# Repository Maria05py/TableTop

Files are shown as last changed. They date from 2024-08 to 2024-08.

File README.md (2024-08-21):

# TableTop
Documentación del proyecto "TableTop" para el evento ExpoCenfo de la Universidad Cenfotec. Este proyecto propone la creación de un prototipo de mesa multifuncional que maximiza el uso de sistemas ciberfísicos, promoviendo el bienestar y acercando la tecnología a distintas generaciones.

## Olimpiadas de Computación inteligente (ExpoCenfo)
El presente proyecto forma parte de uno de los tantos equipos participantes de las Olimpiadas de Computación inteligente, la cual corresponden a una competencia costarricense con sede en la Universidad Cenfotec, abierta a todos los estudiantes universitarios entusiastas de la tecnología que deseen aceptar el reto y competir en la mejor creación de un sistema ciberfísico. Dicho evento tiene lugar el día miércoles 21 de agosto con cede en la Universidad Cenfotec. El sitio oficial del evento, incluyendo las normativas y demás especificaciones, se encuentran en el siguiente enlace: [link](https://ucenfotec.ac.cr/expocenfo/).

## ¿Qué es TableTop?
Este proyecto se centra en una mesa con un display de luces LED, diseñada para ayudar a niños pequeños a mejorar su ansiedad, habilidades motoras y atención. La mesa utiliza sensores infrarrojos para encender, apagar y controlar las luces, lo que permite su uso en juegos de rapidez, concentración y diversas terapias. Además, se integra una aplicación móvil que permitirá cambiar las luces, seleccionar juegos y gestionar funciones básicas a través de tecnología RFID. A futuro también se contempla el uso de Alexa para comandos de voz, proporcionando instrucciones y funcionalidades accesibles para los más pequeños. Adicionalmente, se busca la posibilidad de actualizar juegos y características desde la nube, manteniendo la mesa al día con nuevas opciones. La mesa no es solo un espacio físico, sino un entorno terapéutico y de aprendizaje que utiliza tecnología avanzada para ofrecer experiencias cercanas al uso de la tecnología.
El propósito principal de esta mesa inteligente es crear un entorno seguro y atractivo para que los niños de la casa puedan aprender y relajarse al mismo tiempo. Permitiendo a los niños interactuar con la tecnología en un ambiente controlado, esta mesa inteligente permitirá a los más pequeños de la casa practicar sus habilidades tecnológicas y mejorar su enfoque a través de juegos interactivos y estimulantes a través del uso de luces LEDs, todo esto sin exponerlo a los niños a las redes sociales y aplicaciones con contenido inapropiado y violencia, permitiéndoles estar educados, entretenidos y seguros en el mundo online. 
Los beneficios de este proyecto para los niños de la casa son:

-**Desarrollo de habilidades cognitivas y motoras:** Esta mesa incorpora la diversión y el aprendizaje por medio de juegos que requieren concentración y resolución de problemas, como Tetris o patrones de luz, lo que les ayuda a desarrollar habilidades cognitivas como la memoria, la lógica, la concentración y el pensamiento crítico.

-**Habilidades Tecnológicas:** Ayuda a los niños a familiarizarse con la tecnología en un entorno seguro mientras les ayuda a desarrollar habilidades tecnológicas tempranas, lo que es crucial en el mundo actual.

-**Relajación por medio de estimulación sensorial controlada:** 
La luz suave y los patrones de color cambiantes crean un ambiente sensorial que promueve la calma y la concentración.

-**Aulas interactivas:** La mesa busca convertirse en una herramienta ideal para aulas interactivas, donde los estudiantes pueden participar en actividades grupales o individuales que fomenten la colaboración, la concentración y el aprendizaje a través de la tecnología. Para futuras aplicaciones nuestra mesa inteligente tiene el potencial de ser una herramienta poderosa no solo en el hogar, sino también en entornos educativos y terapéuticos.
****
El presente proyecto es un prototipo equipado con las funcionalidades básicas de: Conectarse a su debida aplicación, mostrar patrones de movimiento en el display LED y reaccionar ante los estímulos de los sensores infrarojos. 

## Índice de Contenido
1. [Organización del repositorio](#Organización-del-repositorio)
2. [Diseño 3D](#diseño-3d)
3. [Materiales no electrónicos](#materiales-no-electrónicos)
4. [Materiales electrónicos](#materiales-electrónicos)
5. [Pasos y creación ](#pasos-y-creación)
6. [Códigos y librerías empleadas](#códigos-y-librerías-empleadas)
7. [Usos y problemas detectados](#Usos-y-problemas-detectados)
8. [Licencia](#licencia)

## Carpetas y organización del repositorio:
**"Códigos":**
- Los archivos tipo C++, header, librerías y .ino necesarios para la correcta ejecución de las diferentes funcionalidades de la mesa.
- Módulos y librerías empleadas para la correcta ejecución del código principal.

**"Modelos3D":**
- Archivos correspondentes a las piezas a cortar por medio de la cortadora láser (Piezas_Superiores.skp)
- Archivos correspondientes al modelo 3D de la mesa completa (Base_mesa_en_melamina.skp)  

**"Licencia":**
- Licencia del presente proyecto y detalles sobre las restricciones correspondientes. 

**"APKs":**
- Archivo apk correspondiente a la debida aplicación de Table Top.
  
**"Documentos":**
- Presentación de los integrantes, detalles sobre el proyecto, implementación y resultados obtenidos.

**"Créditos y atribuciones":**
- Créditos sobre el contenido modifivado y utilizado dentro del código, además de los enlaces correspondientes al contenido original.

## Diseño 3D:
El diseño 3D, a cargo del estudiante Braulio Garro Marín, fue creado desde 0 en el software "SketchUp". A continuación se muestran las dimensiones y el diseño general de la mesa, además de las piezas a cortar para el acabado final, en este caso melamina. 

Imagen de WhatsApp 2024-06-18 a las 14 02 02_3d3d445a
Imagen de WhatsApp 2024-06-18 a las 14 02 02_32868ecb
Imagen de WhatsApp 2024-06-18 a las 14 02 03_3f1b13b2
Imagen de WhatsApp 2024-06-08 a las 18 51 28_593eec7b
Imagen de WhatsApp 2024-06-08 a las 18 51 59_6e4e2997
Imagen de WhatsApp 2024-08-16 a las 15 52 16_07ad1a83

## Materiales no electrónicos:
- Melamina (2500mm x 1830mm).
- MDF (122cm x 244cm).
- Lámina de acrílico de 7mm de grosor (66.4cm x 66.4cm).
- Polarizado translúcido (1m x 1m)
  
## Materiales electrónicos:
- Placa de desarrollo ESP32.
- Cargador de iones de litio multicelda 2S, 3S, 4S.
- uJPM TXS0108E 8-Channel Logic Level Bi-Directional Converter.
- Convertidor buck ajustable de 1000W.
- Tira de luces LED WS2811 (100 LEDs utilizados en este caso).
- Módulo de placa multiplexor digital analógico (7 utilizados en este caso).
- Módulo de sensor de evitación infrarrojo IR (x100 sensores de evitación en este caso).
- Módulo RFID.
- Etiqueta universal ultraligera de 25mm.
- Cable de cobre de distintos grosores.
- Estaño.
- Cables (Preferiblemente de gran cantidad de colores en pro de mejorar la simplicidad de los pasos). 
  
## Pasos y creación:
Una vez cortadas y listas las piezas, se procede a armar la mesa en su totalidad: Unión de cada parte de la melamina (base de la mesa), uniones entre los separadores de la matriz (correspondientes a las "dentaduras"), etc... 






1) Enlistados en orden, con respecto a los componentes electónicos, primeramente se deben de calibrar los 100 sensores infrarrojos para que los mismos reaccionen ante una distancia similar al momento de pasar la mano por encima de los infrarrojos correspondientes, esto se logra ajustando el "Distance Adjust" (Mirar la imagen de referencia).




(Uso de la protoboard para calibrar los 100 sensores infrarojos a utilizar. Se recomienda el uso de la protoboard para probar al menos 5-6 seonsores infrarojos a la vez en pro de agilizar el proceso de creación).

2) Seguidamente, se procede a cortar cable de 3 tres colores diferentes (En nuestro caso rojo, verde y negro) de 5cm, esto con el fin de "alargar" la tira de LEDs, de modo en la que los mismos encajen correctamente en las divisiones de la matriz (líneas de mdf). Estos colores se utilizan para conectar correctamente cada uno de los pines de la tira de LED (5V, GRN y DO) respectivamente. Como es lógico, primero se debe de cortar cada uno de los LEDs de forma en la que cada uno está "suelto".


   
Imagen de WhatsApp 2024-08-20 a las 17 43 21_59c6724c

A continuación, una imagen correspondiente a los pinouts, importante para obtener una mejor referencia, así como los colores y orientación utilizados, recordando la     utilización de cables de 5cm como separación.

 

Imagen de WhatsApp 2024-08-20 a las 17 44 42_55fda35c
(Imagen de referencia: Colores y lógica detrás de las conexiones entre los respectivos leds)



4) Luego, una vez preparados los LEDS, se deben de pegar con silicón caliente los 100 sensores infrarrojos a los separadores de la matriz. Seguidamente se sueldan los pines GND y 5+ entre sí (conectando cada pin con el del siguiente sensor, bajo la lógica GND -> GND del siguiente sensor, por ejemplo) como es posible observar en las siguientes fotografías. Una vez aplicada la corriente respectiva, y al haber calibrado correctamente cada uno de los infrarojos, debe activarse al acercar la mano, incluso tras utilizar el acrílico.


Imagen de WhatsApp 2024-08-11 a las 13 56 32_f2a4d858
Imagen de WhatsApp 2024-08-11 a las 13 56 32_85e9ffc6
Imagen de WhatsApp 2024-08-15 a las 14 14 28_cd028e31


5) Con el propósito de probar la lógica detrás de la matriz LED, fue utilizada una mini matriz de pruebas, la cual consiste en 10 tiras de 10 leds sin cortar ni alterar. A nivel de código fue utilizda la versión de "LEDMatrix.ino" editada por Matthew Kaye. El código original se puede encontrar en el siguiente enlace, el cual debe descargarse como .zip: https://github.com/N00d13/10x10_LED_MATRIX_ANIMATIONS. (Paso opcional). La lógica detrás de la conexiones se puede observar en las conexiones mostradas en la siguiente imagen:

placa de pruebas
Imagen de WhatsApp 2024-08-11 a las 13 56 32_20282ce5

6) Una vez probada la eficacia de la matriz LED, para crear el display final se colocan las respectivas tiras de LEDs previamente preparadas (en este caso, las tiras alteradas con su debida separación de 5cm) de forma en la cual cada led quede centrado con respecto a su respectiva. Las conexiones entre cada una de las tiras se encuentran escondidas debajo de la base, sin embargo, son las mismas mostradas en la mini matriz de prueba. 
   
Imagen de WhatsApp 2024-08-16 a las 23 11 40_c0f88f87
Imagen de WhatsApp 2024-08-16 a las 23 14 34_636a6f1e
(Antes de completar el proceso de montaje del display, se recomienda comprobar el estado de todos los LEDs de la matriz).

Imagen de WhatsApp 2024-08-17 a las 18 15 02_96942961
Imagen de WhatsApp 2024-08-18 a las 12 11 58_bb98c2f2
Imagen de WhatsApp 2024-08-18 a las 16 06 51_b8d5f709
(Proceso de creación de las animaciones de inicio de la aplicación)

7) Una vez se posean los LEDs debidamente pegados, se debe colocar por encima la matriz de MDF, de modo en la que es posible visualizar tanto la matriz de LEDs como el mapeado de infrarojos correspondiente. 

8) Es necesaria efectuar la conexión de los sensores infrarojos para el mapeado LED-Infrarojo, para esto, una vez conectados los dos pines anteriormente mencionados (GND y 5+) entre las distintas filas de infrarojos (paso número 4), es hora de soldar un cable de larga longitud a cada uno de los pines faltantes, el pin "out", de forma en la que posea un cable soldado de una única punta. El cable soldado va a sobresalir en forma de arco como en la siguiente fotografía, por ende, debe estar soldado solamente en el pin. 


9) Seguidamente, es necesario abrir un agujero al lado izquierdo de cada infrarojo, justo en la base donde se pegaron previamente los LEDs.
    
Imagen de WhatsApp 2024-08-20 a las 20 53 51_df8963d6

10) Aprovechando los agujeros abiertos, se debe de "pasar" el cable del pin out, de modo que el mismo se "oculte" y sea pasado por debajo la base, la cual contiene los LEDs.
    
Imagen de WhatsApp 2024-08-20 a las 20 53 50_c17e81a9
Imagen de WhatsApp 2024-08-20 a las 20 53 50_81a2a1f4

11) Seguidamente, se utilizan 7 multiplexors, de forma en la que se mapea cada infrarojo de 16 en 16, a modo de "mapear" e identificar cada uno de los LEDs según su ubicación y estado. Las siguientes imágenes ejemplifican la forma en la que se llevó a cabo este proceso de soldadura.

Imagen de WhatsApp 2024-08-20 a las 20 53 50_079f733d

11) Se coloca el polarizado translúcido encima del acrílico.

polarizado

13) Se deben cargar los respectivos códigos.


    
## Códigos, mapeados y librerías empleadas:

**"Librerías empleadas":**

- *FastLED*: Es necesaria la utilización de la presente librería para crear códigos eficientes, sencillos y optimizados que controlen diferentes modelos de tiras LED, como la WS2811, utilizada por nuestro grupo de trabajo. Esta librería permite trabajar con siglas de composición de los colores primarios (RGB por defecto) y alterarlos, ajustar la intensidad de los LEDs, emplear funciones rápidas y eficientes, superiores a las por defecto de Arduino. Creada por Daniel Garcia.
  
- *MFRC522*: Bilbioteca para la comunciación mediante RFID, haciendo posible la lectura y escritura de etiquetas RFID.
   
- *FastLED_NeoMatrix*: Extensión de FastLED, encargada de controlar la matriz de luces de manera más intuitiva.
  
- *Adafruit_GFX*: Biblioteca gráfica para el uso de LEDs en general. Funciona correctamente al utilizarla en conjunto con las bibliotecas anteriormente mencionadas.
  
- *BluetoothSerial*: Biblioteca encargada de permitir la comunicación Bluetooth mediante el ESP32. En este caso es utilizada para conectar el APK "TableTop".
  
- *LEDMatrix*: Biblioteca encargada de apoyar la lógica de la matriz y permitir el manejo de coordenadas de manera más sencilla.
  
- *LEDSprites*: Biblioteca encargada de permitir la manipulación de gráficos dentro de una matriz (Créditos a AaronLiddiment).
  
- *LEDText*: Biblioteca encargada de poder mostrar texto en la matriz lED (Créditos a AaronLiddiment).
  
- *FontMatrise*: Biblioteca encargada de ajustar la resolución y tipografía del texto mostrado dentro del tetris. 

**"Mapeado de los lEDs":**

La lógica (x,y) de la matriz LED de 10x10 es la siguiente:

	9,  10,  29,  30,  49,  50,  69,  70,  89,  90,
	8,  11,  28,  31,  48,  51,  68,  71,  88,  91,
	7,  12,  27,  32,  47,  52,  67,  72,  87,  92,
	6,  13,  26,  33,  46,  53,  66,  73,  86,  93,
	5,  14,  25,  34,  45,  54,  65,  74,  85,  94,
	4,  15,  24,  35,  44,  55,  64,  75,  84,  95,
	3,  16,  23,  36,  43,  56,  63,  76,  83,  96,
	2,  17,  22,  37,  42,  57,  62,  77,  82,  97,
	1,  18,  21,  38,  41,  58,  61,  78,  81,  98,
	0,  19,  20,  39,  40,  59,  60,  79,  80,  99

En casos en los que es necesario dibujar directamente sobre la matriz, es necesario conocer esta lógica. Además, en caso de mapear cada uno de los sensores, es indispensable conocer esta información. 

## Usos y problemas detectados:

- Se detecta alto nivel de consumo por parte del conjunto de LEDs e infrarojos. Si bien es posible ejecutar el código .ino y aprovechar todas las funcionalidades, no es posible hacer que el uso de baterías alimente correcta y prolongadamente el proyecto. Estos detalles quedan a revisión.
- Existen algunos conflictos con la lectura de la tarjeta RFID en algunos casos, sin embargo, se trata de un tema relacionado al código y al timing de lecturas.

## Participantes:
- Braulio Garro Marín
- María Jesús Rodríguez Molina
- Geisel Thais Hernández Quesada
- Melina Valeska Soto Badilla
  
## Licencia:
Este proyecto está licenciado bajo los términos de la Licencia Creative Commons. 



TableTop © 2024 by TableTop is licensed under CC BY-SA 4.0. To view a copy of this license, visit https://creativecommons.org/licenses/by-sa/4.0/

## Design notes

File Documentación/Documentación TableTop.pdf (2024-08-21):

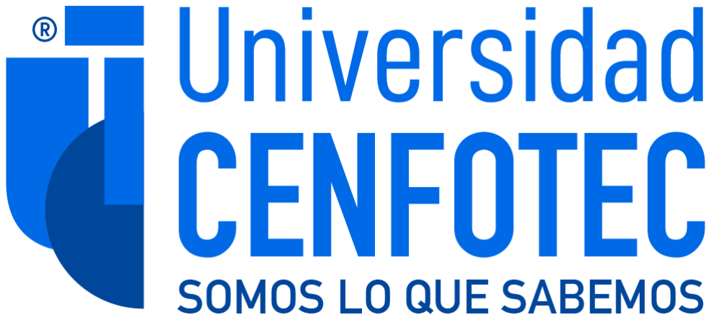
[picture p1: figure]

TableTop

Braulio Garro Marín

María Jesús Rodríguez Molina

Geisel Thais Hernández Quesada

Melina Valeska Soto Badilla

Universidad CENFOTEC

Olimpiadas Computacionales

Fecha: Agosto, 2024

## Índice

Índice | 2
Introducción | 3
Objetivos Específicos | 4
¿Qué es TableTop? | 5
Funcionalidades principales | 5
Fundamentos Tecnológicos Utilizados | 6
Enfoque en el Bienestar del Usuario | 7
Relevancia de nuestro proyecto en el contexto actual | 7
Futuras Aplicaciones | 8

## Introducción

El proyecto TableTop tiene como propósito principal crear un entorno seguro, atractivo y

estimulante para que los niños puedan aprender y relajarse. Esta mesa inteligente está

diseñada para integrar la tecnología de manera controlada en la vida de los más pequeños,

promoviendo tanto el desarrollo de habilidades cognitivas y motoras, como el bienestar

emocional a través de juegos interactivos y terapias basadas en luces LED. En un mundo

donde el acceso a la tecnología está al alcance de todos sin restricción alguna, hace que los

niños estén expuestos a grandes peligros cuando no son supervisados correctamente,

TableTop se presenta como una herramienta que les permite interactuar con dispositivos

tecnológicos de manera constructiva e integral, manteniéndolos seguros de la exposición

excesiva a redes sociales y contenido inapropiado.

Los beneficios de este proyecto para los niños de la casa son:

-Desarrollo de habilidades cognitivas y motoras:Esta mesa incorpora la diversión y el

aprendizaje por medio de juegos que requieren concentración y resolución de problemas,

como Tetris o patrones de luz, lo que les ayuda a desarrollar habilidades cognitivas como la

memoria, la lógica, la concentración y el pensamiento crítico.

-Habilidades Tecnológicas: Ayuda a los niños a familiarizarse con la tecnología en un

entorno seguro mientras les ayuda a desarrollar habilidades tecnológicas tempranas, lo que

es crucial en el mundo actual.

-Relajación por medio de estimulación sensorial controlada: La luz suave y los patrones de

color cambiantes crean un ambiente sensorial que promueve la calma y la concentración.

## Olimpiadas de Computación inteligente (ExpoCenfo)

El presente proyecto forma parte de uno de los tantos equipos participantes de las

Olimpiadas de Computación inteligente, la cual corresponden a una competencia

costarricense con sede en la Universidad Cenfotec, abierta a todos los estudiantes

universitarios entusiastas de la tecnología que deseen aceptar el reto y competir en la mejor

creación de un sistema ciberfísico. Dicho evento tiene lugar el día miércoles 21 de agosto

con sede en la Universidad Cenfotec. El sitio oficial del evento, incluyendo las normativas y

demás especificaciones, se encuentran en el siguiente enlace: link.

## Objetivos Específicos

- Crear una herramienta funcional que beneficie tanto a niños como adultos en el

desarrollo y mejora del pensamiento crítico, de habilidades cognitivas, motoras y de

concentración.

- Promover el uso de tecnologías en el aprendizaje de forma sana e integral.
- Construir una herramienta que funcione tanto en los hogares como en las escuelas

con la función de promover ambientes tranquilos y estimulantes que ayudan a los

usuarios que la utilizan a calmar la ansiedad por medio de juegos de concentración y

luces led.

## ¿Qué es TableTop?

Este proyecto se centra en una mesa interactiva equipada con un display de cien luces LED

y sensores infrarrojos, diseñada para ayudar a niños pequeños a mejorar su ansiedad,

habilidades motoras y atención. La mesa utiliza sensores infrarrojos para encender, apagar

y controlar las luces, lo que permite su uso en juegos de rapidez, concentración y diversas

terapias. Además, se integra una aplicación móvil que permitirá cambiar las luces,

seleccionar juegos y gestionar funciones básicas a través de tecnología RFID.A través de

juegos que requieren rapidez, concentración y habilidades motoras, la mesa ofrece una

plataforma de aprendizaje y relajación.

Funcionalidades principales:

- Sensores infrarrojos: Estos sensores controlan el encendido y apagado de las

luces LED, permitiendo que los niños interactúen con la mesa mediante gestos

simples, como colocar la mano sobre los sensores.

- Aplicación móvil y tecnología RFID: La mesa se integra con una aplicación móvil

que permite cambiar los patrones de luces, seleccionar juegos y gestionar funciones

básicas. Además, la tecnología RFID facilita el acceso a funciones personalizadas y

seguras.

Además, a futuro se espera la integración de las siguientes funcionalidades:

- Comandos de voz con Alexa (futuro): Se contempla la integración de comandos

de voz mediante Alexa, facilitando el acceso a instrucciones y juegos para los más

pequeños.

- Actualizaciones en la nube: Se busca que la mesa pueda mantener

actualizaciones de su juegos y características desde la nube, manteniendo la mesa al día con nuevas opciones y asegurando las mejores prácticas de seguridad para

siempre resguardar la integridad del usuario.

TableTop no es solo un objeto físico, sino un entorno terapéutico y de aprendizaje avanzado,

diseñado para brindar experiencias positivas con la tecnología, alejadas de los peligros del

mundo online.

## Fundamentos Tecnológicos Utilizados

El desarrollo de TableTop se basó en una combinación de tecnologías avanzadas que

permiten su funcionamiento seguro y efectivo:

- Luces LED: Utilizadas para crear patrones visuales interactivos que estimulan el

aprendizaje y la relajación.

- Sensores infrarrojos: Detectan la presencia de la mano del niño para activar los

juegos y las respuestas visuales.

- Tecnología RFID: Se utiliza para mostrar imagenes de inicio y finalización
- Aplicación móvil: Facilita la interacción remota con la mesa, permitiendo a los

padres o educadores ajustar los juegos y las actividades.

- Conectividad con la nube: Utilizado para mantener a la mesa siempre actualizada

con los últimos juegos y terapias disponibles.

- Integración con asistentes de voz (Alexa): Facilita la interacción con la mesa

mediante comandos de voz, haciendo que las funciones sean accesibles incluso

para los más pequeños.

## Enfoque en el Bienestar del Usuario

El bienestar individual y comunitario es el eje central de TableTop. Este proyecto se propone

brindar espacios donde los niños puedan relajarse y aprender seguramente. Una luz suave

con patrones interactivos está diseñada para reducir la ansiedad y mejorar la concentración,

mientras que los juegos promueven habilidades cognitivas y motoras sin necesidad de

exposición a redes sociales o juegos con contenido inapropiado.TableTop tiene un fuerte

enfoque en el bienestar comunitario, ya que está pensada para poder ser usada tanto en los

hogares como en entornos educativos y terapéuticos; por lo tanto, el potencial de este

proyecto para ayudar a una amplia gama de usuarios es enorme. Desde familias que

buscan un entorno seguro para sus hijos hasta escuelas y centros de terapia que desean

integrar la tecnología en su trabajo.

## Relevancia de nuestro proyecto en el contexto actual

En la actualidad, el uso de las tecnologías en la educación ha ido en incremento, sin

embargo, el uso apropiado de estas se ha visto afectado por el auge de las redes sociales,

de los videojuegos violentos y todo tipo de aplicaciones que en lugar de promover el

desarrollo integral de los infantes, lo detiene.Por esa razón, el desarrollo de una herramienta

tan versátil como TableTop, que se puede utilizar para desarrollar las habilidades motoras,

de concentración y cognitivas de los niños y niñas de una forma segura y estimulante, es

tan importante.Esto la posiciona como una herramienta vital en esta creciente era digital. El

gran espectro de usos que tiene TableTop lo convierte en una herramienta importante por su

capacidad para mejorar el bienestar individual y comunitario. En un momento en que la

salud mental y la educación personalizada son prioridades crecientes, TableTop ofrece una

solución que integra ambas en un único dispositivo.

## Futuras Aplicaciones

TableTop tiene el potencial de evolucionar y adaptarse a nuevas necesidades y contextos:

- Aulas Interactivas: Convertir la mesa en una herramienta educativa en el aula,

donde los estudiantes puedan participar en actividades grupales e individuales,

fomentando la colaboración y el aprendizaje.

- Terapia para Niños con Necesidades Especiales: Aplicar las funcionalidades de la

mesa para ayudar a niños con condiciones como el autismo o el TDAH, utilizando la

luz y los juegos para mejorar su enfoque y reducir la ansiedad.

- Expansión de Juegos y Terapias: A través de actualizaciones en la nube, TableTop

puede seguir ofreciendo nuevas experiencias que mantengan a los niños

comprometidos y aprendiendo de manera segura.

El propósito principal de esta mesa inteligente es crear un entorno seguro y atractivo para

que los niños de la casa puedan aprender y relajarse al mismo tiempo. Permitiendo a los

niños interactuar con la tecnología en un ambiente controlado, esta mesa inteligente

permitirá a los más pequeños de la casa practicar sus habilidades tecnológicas y mejorar su

enfoque a través de juegos interactivos y estimulantes a través del uso de luces LEDs, todo

esto sin exponerlo a los niños a las redes sociales y aplicaciones con contenido inapropiado

y violencia, permitiéndoles estar educados, entretenidos y seguros en el mundo online.

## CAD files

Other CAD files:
Modelos3D/Base_mesa_en_melamina.skp
Modelos3D/Piezas_Superiores.skp

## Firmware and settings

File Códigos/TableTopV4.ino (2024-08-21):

// Archivos y librerías necesarias para el funcionamiento del proyecto

#include <SPI.h>
#include <MFRC522.h>
#include <FastLED.h>
#include <FastLED_NeoMatrix.h>
#include <Adafruit_GFX.h>
#include "BluetoothSerial.h" 
#include <LEDMatrix.h>
#include <LEDSprites.h>
#include <LEDText.h>
#include <FontMatrise.h>

#include "Plasma.cpp" 
#include "Lines.cpp"
#include "InterruptHandler.h"

#define DATA_PIN 27 //Pin utilizado en la placa (En este caso ESP32)
#define WIDTH 10 //Ancho de la matriz
#define HEIGHT 10 //Altura de la matriz
#define NUM_LEDS WIDTH * HEIGHT //Tamaño total de la matriz
#define BRIGHTNESS 240 //Brillo o intensidad de la matriz, recordando que el máximo es 255
#define FRAMES_PER_SECOND  120 //Dato necesario para el método doMultipleAnimations. Mientras más bajo el número, más lenta la animación.

//Codigo para tetris

#define LED_PIN        27
#define COLOR_ORDER    GRB
#define CHIPSET        WS2811
#define MATRIX_WIDTH   10
#define MATRIX_HEIGHT  10
#define MATRIX_TYPE    HORIZONTAL_MATRIX

CRGB leds[NUM_LEDS];

// Pines de control para los multiplexores
const int muxS0 = 26;  // Pin de selección S0
const int muxS1 = 25;  // Pin de selección S1
const int muxS2 = 33;  // Pin de selección S2
const int muxS3 = 32;  // Pin de selección S3

const int muxSIG[] = {13, 12, 35, 34, 15, 2, 4}; // Array de pines de señal para 7 multiplexores

// Cambiado de WS2812B a WS2811 ya que esta es la tira LED utilizada para el proyecto
FastLED_NeoMatrix *matrix = new FastLED_NeoMatrix(leds, 10, HEIGHT, WIDTH/10, 1, 
  NEO_MATRIX_BOTTOM     + NEO_MATRIX_LEFT +
    NEO_MATRIX_COLUMNS + NEO_MATRIX_PROGRESSIVE + 
    NEO_TILE_BOTTOM + NEO_TILE_LEFT +  NEO_TILE_PROGRESSIVE);

cLEDMatrix<MATRIX_WIDTH, -MATRIX_HEIGHT, MATRIX_TYPE> ledsTetris;


#define TARGET_FRAME_TIME    15  // Desired update rate, though if too many leds it will just run as fast as it can!
#define INITIAL_DROP_FRAMES  20  // Start of game block drop delay in frames

// Bluetooth input
enum btnInput {NONE, ROTATE, DOWN, LEFT, RIGHT};
btnInput currentInput = NONE;

const uint8_t TetrisIData[] = 
{
  // Frame 1
  B8_3BIT(00000000),
  B8_3BIT(00000000),
  B8_3BIT(00000000),
  B8_3BIT(11110000),
  // Frame 2
  B8_3BIT(10000000),
  B8_3BIT(10000000),
  B8_3BIT(10000000),
  B8_3BIT(10000000),
  // Frame 3
  B8_3BIT(00000000),
  B8_3BIT(00000000),
  B8_3BIT(00000000),
  B8_3BIT(11110000),
  // Frame 4
  B8_3BIT(10000000),
  B8_3BIT(10000000),
  B8_3BIT(10000000),
  B8_3BIT(10000000)
};
const uint8_t TetrisIMask[] = 
{
  // Frame 1
  B8_1BIT(00000000),
  B8_1BIT(00000000),
  B8_1BIT(00000000),
  B8_1BIT(11110000),
  // Frame 2
  B8_1BIT(10000000),
  B8_1BIT(10000000),
  B8_1BIT(10000000),
  B8_1BIT(10000000),
  // Frame 3
  B8_1BIT(00000000),
  B8_1BIT(00000000),
  B8_1BIT(00000000),
  B8_1BIT(11110000),
  // Frame 4
  B8_1BIT(10000000),
  B8_1BIT(10000000),
  B8_1BIT(10000000),
  B8_1BIT(10000000)
};
const uint8_t TetrisJData[] = 
{
  // Frame 1
  B8_3BIT(00000000),
  B8_3BIT(00000000),
  B8_3BIT(22200000),
  B8_3BIT(00200000),
  // Frame 2
  B8_3BIT(00000000),
  B8_3BIT(02000000),
  B8_3BIT(02000000),
  B8_3BIT(22000000),
  // Frame 3
  B8_3BIT(00000000),
  B8_3BIT(00000000),
  B8_3BIT(20000000),
  B8_3BIT(22200000),
  // Frame 4
  B8_3BIT(00000000),
  B8_3BIT(22000000),
  B8_3BIT(20000000),
  B8_3BIT(20000000)
};
const uint8_t TetrisJMask[] = 
{
  // Frame 1
  B8_1BIT(00000000),
  B8_1BIT(00000000),
  B8_1BIT(11100000),
  B8_1BIT(00100000),
  // Frame 2
  B8_1BIT(00000000),
  B8_1BIT(01000000),
  B8_1BIT(01000000),
  B8_1BIT(11000000),
  // Frame 3
  B8_1BIT(00000000),
  B8_1BIT(00000000),
  B8_1BIT(10000000),
  B8_1BIT(11100000),
  // Frame 4
  B8_1BIT(00000000),
  B8_1BIT(11000000),
  B8_1BIT(10000000),
  B8_1BIT(10000000)
};
const uint8_t TetrisLData[] = 
{
  // Frame 1
  B8_3BIT(00000000),
  B8_3BIT(00000000),
  B8_3BIT(33300000),
  B8_3BIT(30000000),
  // Frame 2
  B8_3BIT(00000000),
  B8_3BIT(33000000),
  B8_3BIT(03000000),
  B8_3BIT(03000000),
  // Frame 3
  B8_3BIT(00000000),
  B8_3BIT(00000000),
  B8_3BIT(00300000),
  B8_3BIT(33300000),
  // Frame 4
  B8_3BIT(00000000),
  B8_3BIT(30000000),
  B8_3BIT(30000000),
  B8_3BIT(33000000)
};
const uint8_t TetrisLMask[] = 
{
  // Frame 1
  B8_1BIT(00000000),
  B8_1BIT(00000000),
  B8_1BIT(11100000),
  B8_1BIT(10000000),
  // Frame 2
  B8_1BIT(00000000),
  B8_1BIT(11000000),
  B8_1BIT(01000000),
  B8_1BIT(01000000),
  // Frame 3
  B8_1BIT(00000000),
  B8_1BIT(00000000),
  B8_1BIT(00100000),
  B8_1BIT(11100000),
  // Frame 4
  B8_1BIT(00000000),
  B8_1BIT(10000000),
  B8_1BIT(10000000),
  B8_1BIT(11000000)
};
const uint8_t TetrisOData[] = 
{
  // Frame 1
  B8_3BIT(00000000),
  B8_3BIT(00000000),
  B8_3BIT(44000000),
  B8_3BIT(44000000),
  // Frame 2
  B8_3BIT(00000000),
  B8_3BIT(00000000),
  B8_3BIT(44000000),
  B8_3BIT(44000000),
  // Frame 3
  B8_3BIT(00000000),
  B8_3BIT(00000000),
  B8_3BIT(44000000),
  B8_3BIT(44000000),
  // Frame 4
  B8_3BIT(00000000),
  B8_3BIT(00000000),
  B8_3BIT(44000000),
  B8_3BIT(44000000)
};
const uint8_t TetrisOMask[] = 
{
  // Frame 1
  B8_1BIT(00000000),
  B8_1BIT(00000000),
  B8_1BIT(11000000),
  B8_1BIT(11000000),
  // Frame 2
  B8_1BIT(00000000),
  B8_1BIT(00000000),
  B8_1BIT(11000000),
  B8_1BIT(11000000),
  // Frame 3
  B8_1BIT(00000000),
  B8_1BIT(00000000),
  B8_1BIT(11000000),
  B8_1BIT(11000000),
  // Frame 4
  B8_1BIT(00000000),
  B8_1BIT(00000000),
  B8_1BIT(11000000),
  B8_1BIT(11000000)
};
const uint8_t TetrisSData[] = 
{
  // Frame 1
  B8_3BIT(00000000),
  B8_3BIT(00000000),
  B8_3BIT(05500000),
  B8_3BIT(55000000),
  // Frame 2
  B8_3BIT(00000000),
  B8_3BIT(50000000),
  B8_3BIT(55000000),
  B8_3BIT(05000000),
  // Frame 3
  B8_3BIT(00000000),
  B8_3BIT(00000000),
  B8_3BIT(05500000),
  B8_3BIT(55000000),
  // Frame 4
  B8_3BIT(00000000),
  B8_3BIT(50000000),
  B8_3BIT(55000000),
  B8_3BIT(05000000)
};
const uint8_t TetrisSMask[] = 
{
  // Frame 1
  B8_1BIT(00000000),
  B8_1BIT(00000000),
  B8_1BIT(01100000),
  B8_1BIT(11000000),
  // Frame 2
  B8_1BIT(00000000),
  B8_1BIT(10000000),
  B8_1BIT(11000000),
  B8_1BIT(01000000),
  // Frame 3
  B8_1BIT(00000000),
  B8_1BIT(00000000),
  B8_1BIT(01100000),
  B8_1BIT(11000000),
  // Frame 4
  B8_1BIT(00000000),
  B8_1BIT(10000000),
  B8_1BIT(11000000),
  B8_1BIT(01000000)
};
const uint8_t TetrisTData[] = 
{
  // Frame 1
  B8_3BIT(00000000),
  B8_3BIT(00000000),
  B8_3BIT(66600000),
  B8_3BIT(06000000),
  // Frame 2
  B8_3BIT(00000000),
  B8_3BIT(06000000),
  B8_3BIT(66000000),
  B8_3BIT(06000000),
  // Frame 3
  B8_3BIT(00000000),
  B8_3BIT(00000000),
  B8_3BIT(06000000),
  B8_3BIT(66600000),
  // Frame 4
  B8_3BIT(00000000),
  B8_3BIT(60000000),
  B8_3BIT(66000000),
  B8_3BIT(60000000)
};
const uint8_t TetrisTMask[] = 
{
  // Frame 1
  B8_1BIT(00000000),
  B8_1BIT(00000000),
  B8_1BIT(11100000),
  B8_1BIT(01000000),
  // Frame 2
  B8_1BIT(00000000),
  B8_1BIT(01000000),
  B8_1BIT(11000000),
  B8_1BIT(01000000),
  // Frame 3
  B8_1BIT(00000000),
  B8_1BIT(00000000),
  B8_1BIT(01000000),
  B8_1BIT(11100000),
  // Frame 4
  B8_1BIT(00000000),
  B8_1BIT(10000000),
  B8_1BIT(11000000),
  B8_1BIT(10000000)
};
const uint8_t TetrisZData[] = 
{
  // Frame 1
  B8_3BIT(00000000),
  B8_3BIT(00000000),
  B8_3BIT(77000000),
  B8_3BIT(07700000),
  // Frame 2
  B8_3BIT(00000000),
  B8_3BIT(07000000),
  B8_3BIT(77000000),
  B8_3BIT(70000000),
  // Frame 3
  B8_3BIT(00000000),
  B8_3BIT(00000000),
  B8_3BIT(77000000),
  B8_3BIT(07700000),
  // Frame 4
  B8_3BIT(00000000),
  B8_3BIT(07000000),
  B8_3BIT(77000000),
  B8_3BIT(70000000)
};
const uint8_t TetrisZMask[] = 
{
  // Frame 1
  B8_1BIT(00000000),
  B8_1BIT(00000000),
  B8_1BIT(11000000),
  B8_1BIT(01100000),
  // Frame 2
  B8_1BIT(00000000),
  B8_1BIT(01000000),
  B8_1BIT(11000000),
  B8_1BIT(10000000),
  // Frame 3
  B8_1BIT(00000000),
  B8_1BIT(00000000),
  B8_1BIT(11000000),
  B8_1BIT(01100000),
  // Frame 4
  B8_1BIT(00000000),
  B8_1BIT(01000000),
  B8_1BIT(11000000),
  B8_1BIT(10000000)
};

#define TETRIS_SPR_WIDTH  4
#define TETRIS_SPR_HEIGHT 4
const uint8_t *TetrisSprData[] = { TetrisIData, TetrisJData, TetrisLData, TetrisOData, TetrisSData, TetrisTData, TetrisZData };
const uint8_t *TetrisSprMask[] = { TetrisIMask, TetrisJMask, TetrisLMask, TetrisOMask, TetrisSMask, TetrisTMask, TetrisZMask};
const struct CRGB TetrisColours[] = { CRGB(0, 255, 255), CRGB(0, 0, 255), CRGB(255, 165, 0), CRGB(255, 255, 0), CRGB(50, 205, 50), CRGB(255, 0, 255), CRGB(255, 0, 0) };

uint8_t PlayfieldData[MATRIX_HEIGHT * ((MATRIX_WIDTH + 7) / 8) * _3BIT];
uint8_t PlayfieldMask[MATRIX_HEIGHT * ((MATRIX_WIDTH + 7) / 8) * _1BIT];
uint8_t CompletedLinesData[TETRIS_SPR_HEIGHT * ((MATRIX_WIDTH + 7) / 8) * _1BIT];
const struct CRGB CompletedLinesColour[] = { CRGB(255, 255, 255) };
cSprite Playfield, CompletedLines, CurrentBlock;
cLEDSprites Sprites(&ledsTetris);

unsigned char AttractMsg[144], GameOverMsg[88];
char BlankMsg[32];
cLEDText TetrisMsg;

uint8_t DropDelay;
boolean AttractMode, NextBlock;
int16_t TotalLines;
unsigned int HighScore = 0, LastScore;

uint16_t PlasmaTime, PlasmaShift;
uint32_t LoopDelayMS, LastLoop;

//Termina el bloque encargado de trabajar el codigo para tetris

// Empieza el bloque de código para el uso de RFID
#define SS_PIN 5
#define RST_PIN 22
MFRC522 mfrc522(SS_PIN, RST_PIN);  // Crear objeto MFRC522

// Código del "MAIN"
bool cardPresent = false;  // Estado de la tarjeta (si está presente o no)
bool lastCardPresent = false; // Estado previo de la tarjeta

BluetoothSerial SerialBT;

// Colores de texto en un ciclo
const uint16_t colors[] = {
  matrix->Color(255, 87, 51), // Naranja
  matrix->Color(0, 128, 128), // Teal
  matrix->Color(255, 20, 147), // Rosado
  matrix->Color(165, 42, 42)  // Marrón
}; 

bool bluetoothInterrupt = false;
int amountColours = 4; // Número de colores en el ciclo
int x = WIDTH; // Posición inicial del texto
int pass = 0;  // Control para el ciclo de colores
bool firstCardPresent = false;
unsigned long previousMillis = 0;    // Variable para almacenar el tiempo anterior
const long RFIDinterval = 1000;          // Intervalo de 1000 ms (1 segundo)

int SensorMapping[100] = {
  1, 20, 21, 31, 41, 51, 61, 71, 81, 91, 
  2, 19, 22, 32, 42, 52, 62, 72, 82, 92, 
  3, 18, 23, 33, 43, 53, 63, 73, 83, 93, 
  4, 17, 24, 34, 44, 54, 64, 74, 84, 94, 
  5, 16, 25, 35, 45, 55, 65, 75, 85, 95, 
  6, 15, 26, 36, 46, 56, 66, 76, 86, 96, 
  7, 14, 27, 37, 47, 57, 67, 77, 87, 97, 
  8, 13, 28, 38, 48, 58, 68, 78, 88, 98, 
  9, 12, 29, 39, 49, 59, 69, 79, 89, 99, 
  10, 11, 30, 40, 50, 60, 70, 80, 90, 100
};

int sensorState[100];

void setup() {
//Codigo set Multiplexores
  pinMode(muxS0, OUTPUT);
  pinMode(muxS1, OUTPUT);
  pinMode(muxS2, OUTPUT);
  pinMode(muxS3, OUTPUT);
  // Configurar los pines de señal de los multiplexores como entrada
  for (int i = 0; i < 7; i++) {
    pinMode(muxSIG[i], INPUT);
  }

    //Set up Bluetooth
    Serial.begin(115200);
    SPI.begin();  // Iniciar SPI sin especificar pines (Si al compilar sale un error relacionado, no tiene importancia)
    mfrc522.PCD_Init();  // Iniciar MFRC522
    SerialBT.begin("TableTop_BT");
    Serial.println("The device is ready to pair!");
    // Cambiado WS2812B a WS2811 para tu tira LED específica
    FastLED.addLeds<WS2811, DATA_PIN, GRB>(leds, NUM_LEDS); // Configuración específica para WS2811
    matrix->begin(); //Sets up matrix
    matrix->setTextWrap(false);
    matrix->setBrightness(BRIGHTNESS);
    matrix->setTextColor(colors[pass]); // Inicializa con el primer color

	// Recordar los siguientes datos
    //Tetris SETUP
    //Serial.begin(115200); 
    //SerialBT.begin("ESP32Tetris");
    
    //FastLED.addLeds<CHIPSET, LED_PIN, COLOR_ORDER>(ledsTetris[0], ledsTetris.Size());
    //FastLED.setBrightness(200);
    //FastLED.clear(true);
    //FastLED.show();

    memset(PlayfieldData, 0, sizeof(PlayfieldData));
    memset(PlayfieldMask, 0, sizeof(PlayfieldMask));
    Playfield.Setup(ledsTetris.Width(), ledsTetris.Height(), PlayfieldData, 1, _3BIT, TetrisColours, PlayfieldMask);
    Playfield.SetPositionFrameMotionOptions(0, 0, 0, 0, 0, 0, 0, 0, 0);
    Sprites.AddSprite(&Playfield);

    memset(CompletedLinesData, 0, sizeof(CompletedLinesData));
    CompletedLines.Setup(ledsTetris.Width(), TETRIS_SPR_HEIGHT, CompletedLinesData, 1, _1BIT, CompletedLinesColour, CompletedLinesData);
    CompletedLines.SetPositionFrameMotionOptions(0, 0, 0, 0, 0, 0, 0, 0, 0);

    TetrisMsg.SetFont(MatriseFontData);
    sprintf((char *)BlankMsg, "%.*s", _min(((ledsTetris.Height() + TetrisMsg.FontHeight()) / (TetrisMsg.FontHeight() + 1)), (int)sizeof(BlankMsg) - 1), "                              ");
    sprintf((char *)AttractMsg, "%sTETRIS%sSCORE %u%sHIGH %u%sANY BUTTON TO START%s", BlankMsg, BlankMsg, LastScore, BlankMsg, (int)HighScore, BlankMsg, BlankMsg);
    TetrisMsg.Init(&ledsTetris, TetrisMsg.FontWidth() + 1, ledsTetris.Height(), (ledsTetris.Width() - TetrisMsg.FontWidth()) / 2, 0);
    TetrisMsg.SetBackgroundMode(BACKGND_LEAVE);
    TetrisMsg.SetScrollDirection(SCROLL_UP);
    TetrisMsg.SetTextDirection(CHAR_UP);
    TetrisMsg.SetFrameRate(1);
    TetrisMsg.SetOptionsChangeMode(INSTANT_OPTIONS_MODE);
    TetrisMsg.SetText(AttractMsg, strlen((const char *)AttractMsg));
    AttractMode = true;
    LoopDelayMS = TARGET_FRAME_TIME;
    LastLoop = millis() - LoopDelayMS;
    PlasmaShift = (random8(0, 5) * 32) + 64;
    PlasmaTime = 0;

    //En of Tetris SETUP

    FastLED.clear();
}

void loop() {
  //doPlasma(); 
  doSpell("TableTop", -55);
  if (SerialBT.available()) {    // Check if data is available on Bluetooth
    String receivedData = "";    // Variable to hold the received data

    while (SerialBT.available()) {
      receivedData += (char)SerialBT.read();  // Read data byte by byte
      delay(20); // Delay to allow more data to be read if coming in a stream
      
    }

    Serial.println("Received via Bluetooth: " + receivedData); // Print received data to serial port

    // Call the appropriate function based on receivedData
    selectFunction(receivedData);
    //retona a la vista de TableTop
        while (true) {
      if (checkForBluetoothInterrupt()) { // Verifica si hay interrupción
        break; // Sal del bucle si hay datos disponibles en Bluetooth
      }
      doSpell("TableTop", -55);
    }
  }

  cardPresent = mfrc522.PICC_IsNewCardPresent() && mfrc522.PICC_ReadCardSerial();

    // Obtener el tiempo actual
  unsigned long currentMillis = millis();

  if (cardPresent && !lastCardPresent) {
    if (!firstCardPresent) {
      // Si es la primera vez que se coloca la tarjeta
      Serial.println("Card Present"); 
      selectFunction("cardPresent");
      firstCardPresent = true;
    } else {
      // Si es la segunda vez que se coloca la tarjeta
      Serial.println("Card absent");
      selectFunction("cardAbsent");
      firstCardPresent = false;
    }
  }

  if (currentMillis - previousMillis >= RFIDinterval) {
    previousMillis = currentMillis; // Actualizar el tiempo anterior
    lastCardPresent = cardPresent;  // Actualizar el estado previo
    mfrc522.PICC_HaltA();
  }
}

void selectFunction(String data) {
  if (data == "i") {
    while (true) {
      if (checkForBluetoothInterrupt()) { // Verifica si hay interrupción
        break; // Sale del bucle si hay datos disponibles en Bluetooth
      }
      doSpell("TableTop", -55); // Muestra el texto "TableTop"
    }
    
  } else if (data == "p") {
    while (true) {
      if (checkForBluetoothInterrupt()) { // Verifica si hay interrupción
        break; // Sale del bucle si hay datos disponibles en Bluetooth
      }
      doPlasma(); // Ejecuta la función
    }
    } else if (data == "m") { // Lee sensores y controla LEDs
    while (true) {
      if (checkForBluetoothInterrupt()) { // Se verifica si hay interrupción
        break; // Sale del bucle si hay datos disponibles en Bluetooth
      }

      // Leer el estado de los sensores
      leerSensores();

      // Controlar los LEDs según el estado de los sensores
      controlarLEDs();

      // Mantener el estado de los LEDs durante 1 segundo
      delay(100);
    }
  } else if (data == "l") {
    while (true) {
      if (checkForBluetoothInterrupt()) { // Verifica si hay interrupción
        break; // Sal del bucle si hay datos disponibles en Bluetooth
      }
      doLines(); // Ejecuta la función
    }
  } else if (data == "cardPresent") {
    // Ejecuta secuencia de caras cuando la tarjeta está presente
    draw_face1();
    delay(1000);
    text_1();
    delay(1000);

    draw_face2();
    delay(1000);
    text_2();
    delay(1000);

    draw_face3();
    delay(1000);
    text_3();
    delay(1000);

    draw_face4();
    delay(1000);
    text_4();
    delay(1000);
  } else if (data == "cardAbsent") {
    // Ejecuta la animación de despedida cuando la tarjeta no está presente
    draw_sadface1();
    delay(1000);
    draw_sadface2();
    delay(1000); 
    draw_sadface3();
    delay(1000);
    draw_sadface4();
    delay(1000);
    FastLED.clear();
  } else if (data == "t") { //tetr
    bool Gamestatus = true;
      FastLED.addLeds<CHIPSET, LED_PIN, COLOR_ORDER>(ledsTetris[0], ledsTetris.Size());
      FastLED.setBrightness(BRIGHTNESS);
      FastLED.clear(true);
      FastLED.show();
    while (true) {

      Gamestatus = processGameLogic(); // Usa processGameLogic() para determinar el estado del bucle
      if (!Gamestatus) {
        break; // Sal del bucle si processGameLogic() devuelve false
      }
    }
  } else {
    Serial.println("Invalid option received.");
  }
}

void doPlasma() {
    Plasma plasma(leds, WIDTH, HEIGHT);
    plasma.start();
    FastLED.clear(); // Limpia la pantalla después de la animación
}


void doLines() {
    Lines lines(leds, WIDTH, HEIGHT);
    lines.start();
    FastLED.clear(); // Limpia la pantalla después de la animación
}

//doPlasma2 is modified from LDIRKO's Pastbin code found at this link: https://pastebin.com/6xT72A46

void doPlasma2(){
  int plasmaBrightness = 240; //The brightness is lower for doPlasma2. Change the added amount to BRIGHTNESS to your desire.
  int plasmaSpeed = 7; //Speed that the plasma changes colours, larger is slower  
  for (uint16_t time = 0, cycles = 0; cycles < 6521; time += 128, cycles++) { //Cycle is amount of time the animations runs. This runs for ~60 seconds
    uint16_t ms = millis();
    for (int i = 0; i < HEIGHT; i++) {
      for (int j = 0; j < WIDTH; j++) {
        uint8_t index = inoise8(i * 41, j * 41, ms / plasmaSpeed);  // x and y not change, only change z value with time increment for nice plasma looking noise original 4
        leds[XYNumberFind(i, j)] = CHSV((index + ms / 200) % 255, 255, plasmaBrightness); // within palette
      }
    }
    FastLED.delay(1);
  }
  FastLED.clear(); //clears matrix for next animation
}

uint8_t XYNumberFind(uint8_t x, uint8_t y) { return (y * WIDTH + x);}    //Function to find LED coordinates in LED matrix, 

//Next Part is for the multiple animations that are meshed together
//It is a modified version of the FASTLED example library, "DemoReal100"

// Forward declaration for addGlitter to ensure it's recognized before being used
void addGlitter(fract8 chanceOfGlitter);

typedef void (*SimplePatternList[])();
SimplePatternList gPatterns = {rainbow, rainbow, rainbowWithGlitter, confetti, sinelon, juggle, bpm };

uint8_t gCurrentPatternNumber = 0; // Index number of which pattern is current
uint8_t gHue = 0; // rotating "base color" used by many of the patterns

void doMultipleAnimations(){
  gCurrentPatternNumber = 0; // resets the pattern number to 0 every time doMultipleAnimations is called
  bool animationsFinished = false;
  int amountAnimations = 0;
  while(animationsFinished == false){
    gPatterns[gCurrentPatternNumber]();
    // send the 'leds' array out to the actual LED strip
    FastLED.show();  
    // insert a delay to keep the framerate modest
    FastLED.delay(1000/FRAMES_PER_SECOND); 
    // do some periodic updates
    EVERY_N_MILLISECONDS( 20 ) { gHue++; } // cycles the base color through the rainbow
    EVERY_N_SECONDS( 25 ){ // changes animation every n seconds
      nextPattern(); 
      amountAnimations++;
    } 
    if(amountAnimations == 7){
      animationsFinished = true;
    }
  }
  FastLED.clear(); //clears matrix for next animation
}

#define ARRAY_SIZE(A) (sizeof(A) / sizeof((A)[0]))

void nextPattern()
{
  // add one to the current pattern number, and wrap around at the end
  gCurrentPatternNumber = (gCurrentPatternNumber + 1) % ARRAY_SIZE( gPatterns);
}

void rainbow() 
{
  // FastLED's built-in rainbow generator
  fill_rainbow( leds, NUM_LEDS, gHue, 7);
}

void rainbowWithGlitter() 
{
  // built-in FastLED rainbow, plus some random sparkly glitter
  rainbow();
  addGlitter(80);
}

void addGlitter(fract8 chanceOfGlitter) 
{
  if( random8() < chanceOfGlitter) {
    leds[ random16(NUM_LEDS) ] += CRGB::White;
  }
}

void confetti() 
{
  // random colored speckles that blink in and fade smoothly
  fadeToBlackBy( leds, NUM_LEDS, 10);
  int pos = random16(NUM_LEDS);
  leds[pos] += CHSV( gHue + random8(64), 200, 255);
}

void sinelon()
{
  // a colored dot sweeping back and forth, with fading trails
  fadeToBlackBy( leds, NUM_LEDS, 20);
  int pos = beatsin16( 13, 0, NUM_LEDS-1 );
  leds[pos] += CHSV( gHue, 255, 192);
}

void bpm()
{
  // colored stripes pulsing at a defined Beats-Per-Minute (BPM)
  uint8_t BeatsPerMinute = 62;
  CRGBPalette16 palette = PartyColors_p;
  uint8_t beat = beatsin8( BeatsPerMinute, 64, 255);
  for( int i = 0; i < NUM_LEDS; i++) { //9948
    leds[i] = ColorFromPalette(palette, gHue+(i*2), beat-gHue+(i*10));
  }
}

void juggle() {
  // eight colored dots, weaving in and out of sync with each other
  fadeToBlackBy( leds, NUM_LEDS, 20);
  byte dothue = 0;
  for( int i = 0; i < 8; i++) {
    leds[beatsin16( i+7, 0, NUM_LEDS-1 )] |= CHSV(dothue, 200, 255);
    dothue += 32;
  }
}
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
